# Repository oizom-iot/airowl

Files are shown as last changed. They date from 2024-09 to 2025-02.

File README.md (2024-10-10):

<div align="center">

# **AIROWL**

The OIZOM Airowl is an indoor Air Quality Measurement device comprising of the ESP32 S3 powered M5stack Core S3 SE, which integrates the aforementioned controller chip, with a 320 x 240 LCD screen supporting capacitive touch, along with a speaker and the AXP2101 power management chip.

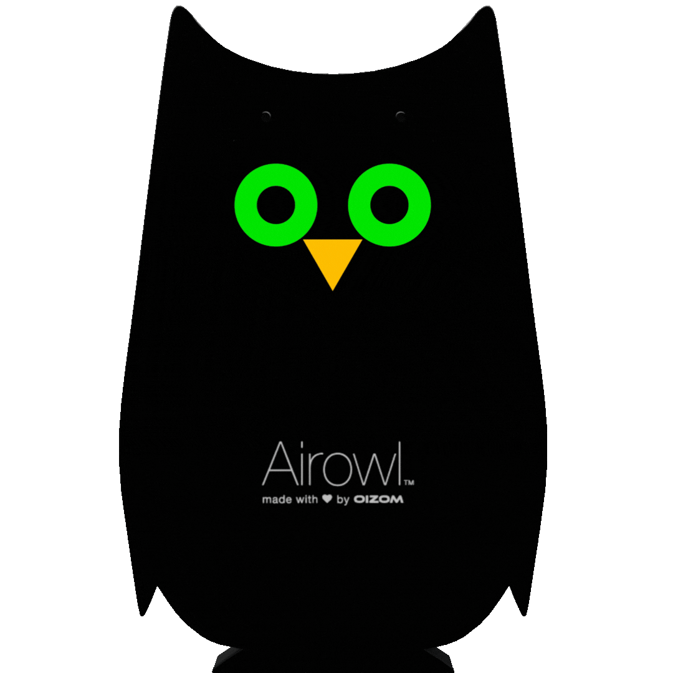
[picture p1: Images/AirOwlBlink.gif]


</div>

This Repository serves as the source of the complete Airowl, consisting of its Firmware source files, 3D files and PCB design Files.

This file provides instructions to assemble the individual components of the Airowl, along with its Bill of Materials (BOM).

The BOM for the Airowl is as Follows:

| SR. | ITEM DESCRIPTION | NOTES | Qty | Product Links |
|-----|---|---|-----|---|
| 1 | M5 STACK | SCREEN | 1 | <a href="https://shop.m5stack.com/products/m5stack-cores3-se-iot-controller-w-o-battery-bottom" target="_blank">Link</a> |
| 2 | FRONT FACIA | UV FRONT 1.3 MM + REAR BLACK 5 MM | 1 | [Front](/Designfiles/Frontfacia) |
| 3 | 3D PRINT BACK CASE | BLACK MATTLE 3D PRINTED CASE | 1 | [Back](/Designfiles/Backcover) |
| 4 | FASTENERS | M3 X 8 mm PHILIPS HEAD (SS) | 2 | |
| 5 | FASTENERS | M3 X 20 mm CSK Blunted (SS) | 2 | |
| 6 | FASTENERS | M3 X 25 mm CSK Blunted (SS) | 2 | |
| 7 | Screw Driver (+) | Mini Screw Driver | 1 | |
| 8 | TYPE C - TYPE C CABLE | PORTRONICS TYPE C CABLE | 1 | |

More details of the individual components can be found as followed:

[PCB files](/Mountingboard/)

[Firmware](/Firmware)

[Squareline studio project files](/squareline/) 

[Design Files](/Designfiles/)

## Assembling the Airowl

The following is a cross sectional view of the Airowl dpicting its individual components and the way that they must be connected:

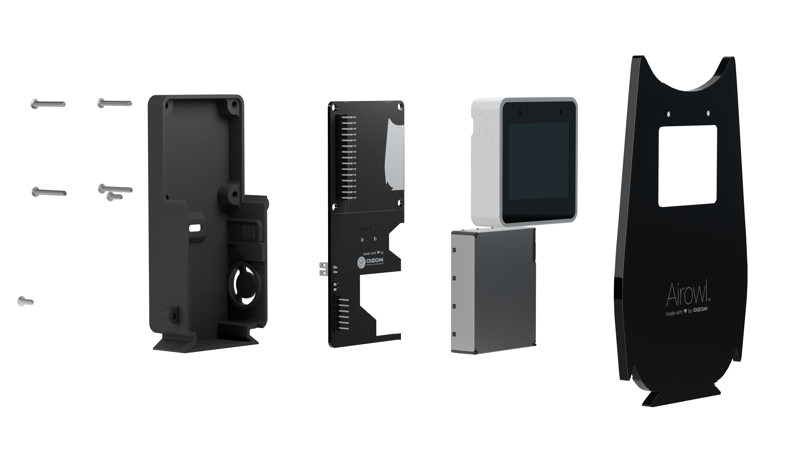
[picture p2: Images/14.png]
Design Files


From left to right, we can observe the parts as follows:

1. Screws
2. [3D printed Black Case](Images/16.png)
3. [Printed circuit Board](Images/19.png)
4. M5 stack Core S3 SE
5. Sensirion SEN 54 sensor
6. [Front Cover](Images/15.png)

Ensure that the screws are connected correctly as depicted in the above picture, incase the screws are connected incorrectly, the longer screws might damage the physical cover of the Airowl.

On assembling the Airowl, it appears like depicted below:



On following the instructions in [Firmware](/Firmware/), the Airowl can be programmed succesfully.

Check this repository releases for newer firmware updates.

## Made by the Community, with -❤️-:

<a href="https://github.com/oizom-iot/airowl/graphs/contributors">
  
</a>

## Licensing

Airowl is available under MIT License

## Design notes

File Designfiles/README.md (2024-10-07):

# Design files

## 3MF File for 3D Printing
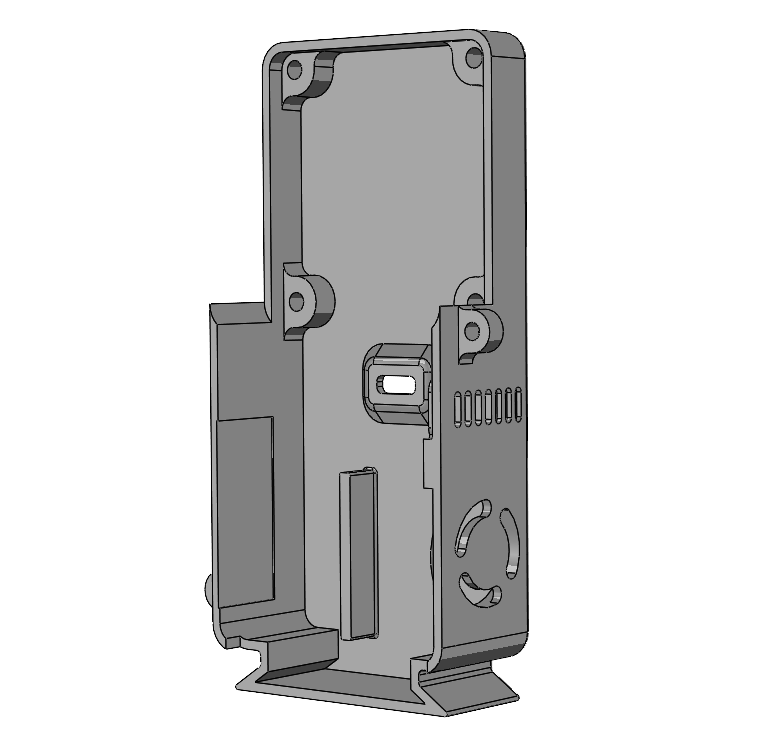
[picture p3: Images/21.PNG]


### Suggestions for 3D printing
- **Material**: PLA+
- **Color**: Matte Black
- **Print Quality**:
  - 0.15mm layer for 0.4mm nozzle
  - Use 0.08mm layer for better quality

## DXF Files for Laser Cutting

- **Transparent Acrylic Sheet (Front Facia)**
  - Thickness: 1mm ± 0.2mm

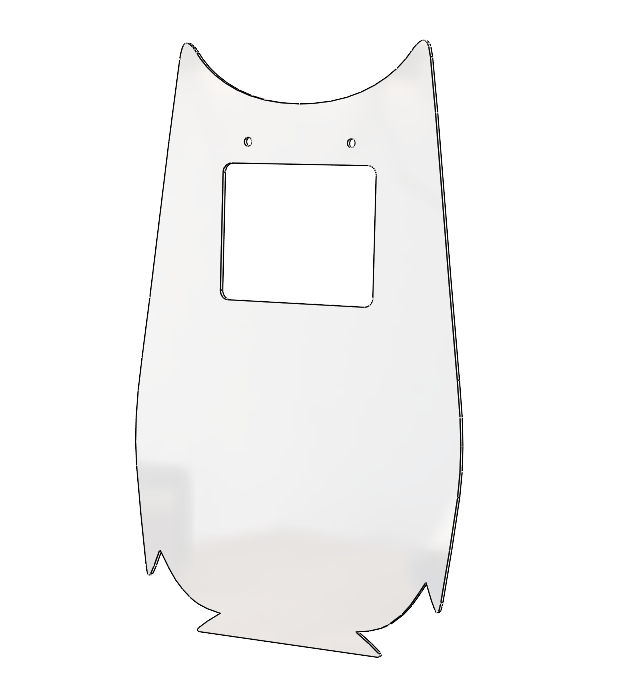
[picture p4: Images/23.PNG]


- **Black Acrylic Sheet (Front Facia)**
  - Thickness: 5mm

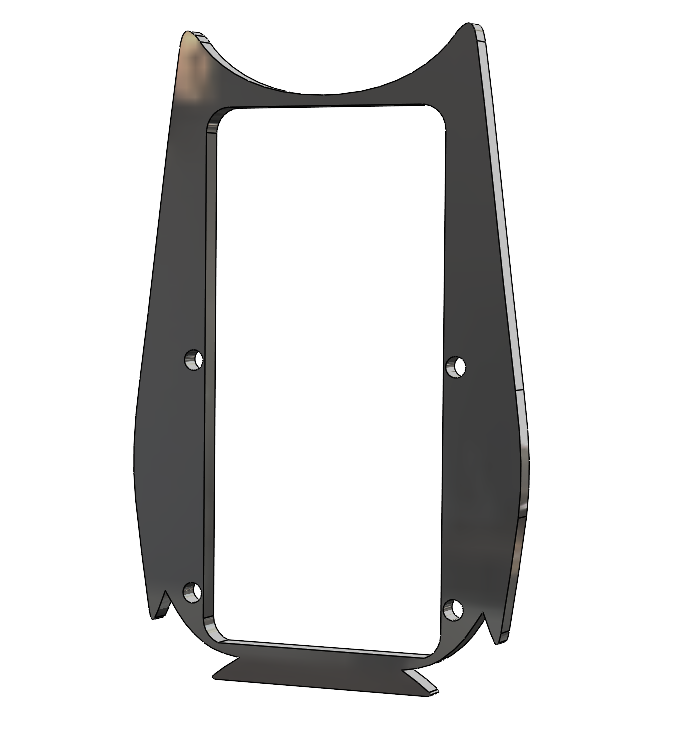
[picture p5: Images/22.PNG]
 

## PDF File for UV Printing

- **Print on transparent Acrylic Sheet**
  - **Color**: Black

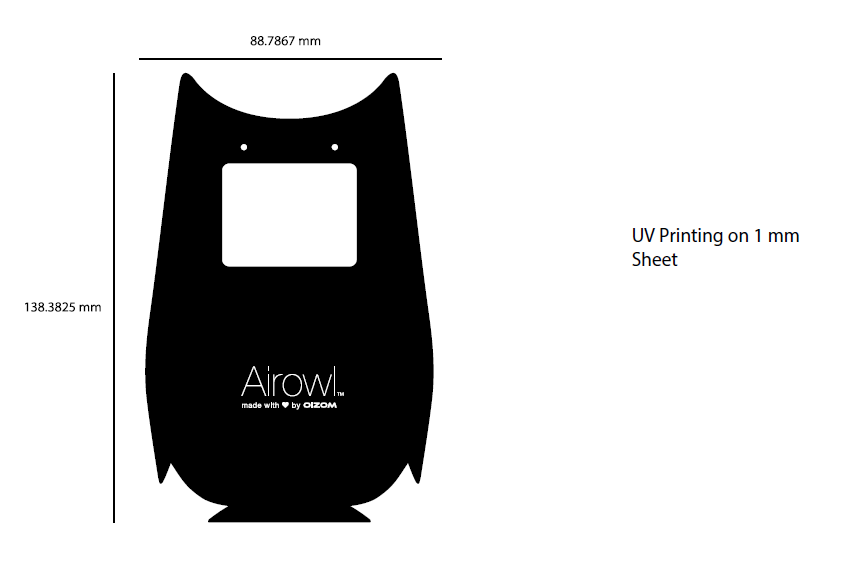
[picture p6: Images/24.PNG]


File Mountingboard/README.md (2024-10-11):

# Open Source PCB Design for M5Stack and Sensirion Dust Sensor SN54





This repository contains the open-source PCB design created using **KiCAD** software. The design includes both the schematic and the PCB layout.

---

## Table of Contents
- [Project Overview](#project-overview)
- [Key Features](#key-features)
- [Schematic and PCB Design](#schematic-and-pcb-design)
  - [Schematic](#schematic)
  - [Rendered PCB Images](#rendered-pcb-images)
- [Bill of Materials (BOM)](#bill-of-materials-bom)
- [How to Use](#how-to-use)
- [Contributing](#contributing)
- [License](#license)

---

## Project Overview

This PCB design integrates the **M5Stack** and the **Sensirion Dust Sensor SN54**, which measures the following parameters:

- **PM1**
- **PM2.5**
- **PM10**
- **Temperature**
- **Humidity**
- **TVOC Index**

The design facilitates I2C communication between the M5Stack and the dust sensor, with electrical connections labeled and organized for simplicity.

### Key Features

- **I2C Communication**: The M5Stack communicates with the Sensirion Dust Sensor via I2C.
- **Type-C Power Supply**: The entire PCB is powered through a Type-C connector.
- **Sensor Connections**: The wires from the sensor are soldered onto the PCB, with labeled footprints for I2C and 5V power connections.

---

## Schematic and PCB Design

The repository includes:

- **Schematic**: Showing the connection between M5Stack and Sensirion Dust Sensor SN54.
- **PCB Design**: Footprint and layout for soldering sensor wires and powering the device.

### Schematic

<details>
  <summary>Click to expand Schematic image</summary>
  
  Schematic

</details>

### Rendered PCB Images

- **Front View**
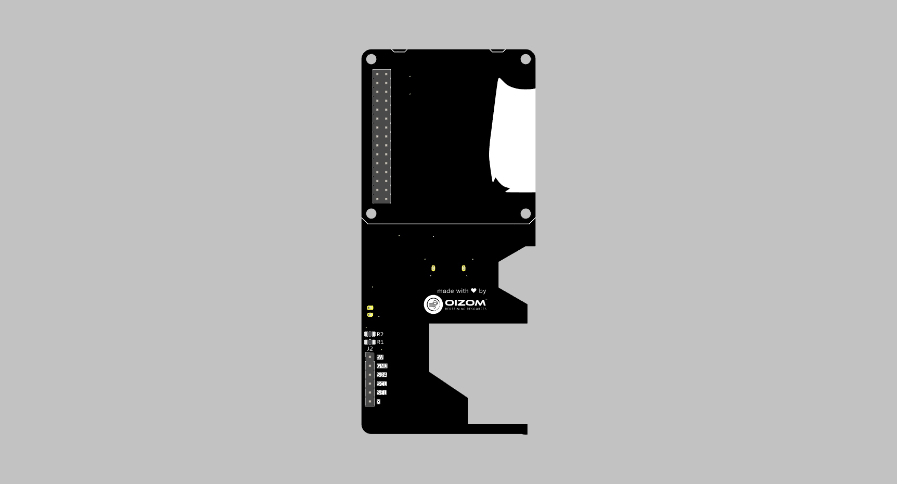
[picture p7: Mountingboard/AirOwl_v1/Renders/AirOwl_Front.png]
Front View


- **Back View**
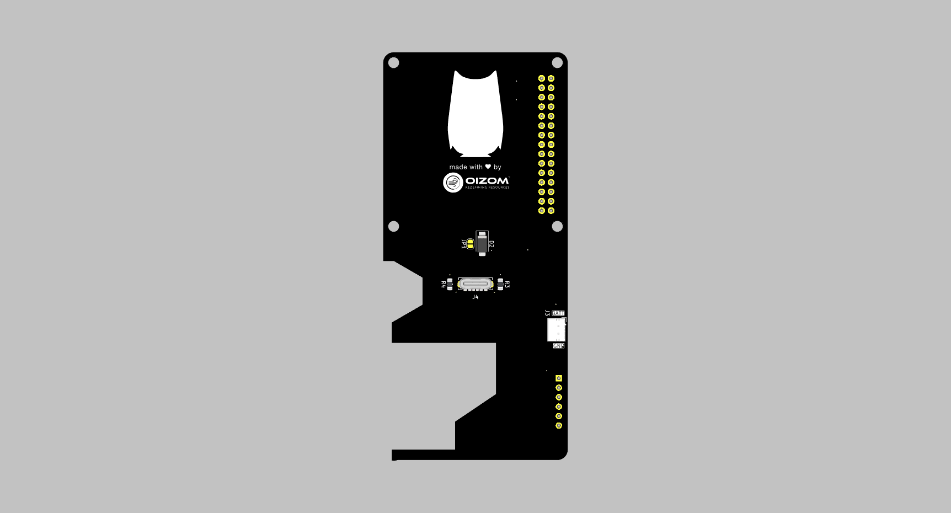
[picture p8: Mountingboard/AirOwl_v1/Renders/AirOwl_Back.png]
Back View


---

## Interactive BOM

You can download the Interactive BOM [here](AirOwl_v1/bom/ibom.html).



> **Note**: Right-click the link and select "Open Link in New Tab" or press `Ctrl + Click` to open in a new tab.

## Bill of Materials (BOM)

| Part Name | Quantity | Reference Link |
|---|---|---|
| **M5Stack CoreS3-SE** | 1 | <a href="https://shop.m5stack.com/products/m5stack-cores3-se-iot-controller-w-o-battery-bottom" target="_blank">Link</a> |
| **Sensirion Dust Sensor SEN54**| 1 |  <a href="https://www.digikey.in/en/products/detail/sensirion-ag/SEN54-SDN-T/15903868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" target="_blank">Link</a> | 
| **Type-C Connector** | 1 |  <a href="https://www.digikey.in/en/products/detail/same-sky/UJC-VP-3-SMT-TR/14310522?productid=14310522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">Link</a> | 
| **I2C Pull-up Resistors [R1, R2]** | 2 | 10K 0805 (Optional) | 
| **Resistors [R3, R4]** | 2 | 4.7K 0805 (Must for Type C PD) | 
| **Male Header Pin** | 1 | 2.54mm 40x2 Male Header Pin | 
| **Sensirion Dust Sensor Cable** | 1 | <a href="https://evelta.com/jst-ghr-06v-cable-6pin-1-25mm-pitch-female-connector-15cm/" target="_blank">Link</a> | 

> **Note:** This table will be updated with detailed part information.

---

## How to Use

To get started with this PCB design:

```bash
# Step 1: Clone the repository
git clone https://github.com/your-repo-name.git

# Step 2: Open the project in KiCAD

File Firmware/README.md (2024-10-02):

# Firmware

This folder contains the firmware files used to program the Airowl. The Folder consists of various folders used by PlatformIO to configure and program the project.

## Using PlatformIO
PlatformIO is a VS code extension that enables us to program microcontrollers using VS code. The PlatformIO core supports more than 1500 development boards including the M5 core S3 used in the Airowl. PlatformIO supports both esp-idf and arduino environments. 

### Step 1  Installing PlatformIO 
PlatformIO can be installed using the extensions feature in Visual Studio Code.

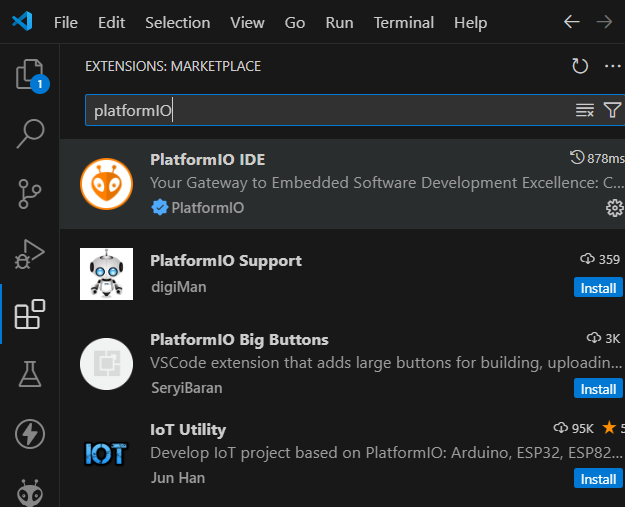
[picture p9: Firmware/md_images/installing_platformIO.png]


### Step 2 Using PlatformIO with Airowl Firmware

In order to program the Airowl with the firmware, download and extract this repository or clone it.
Open platformIO using the platformIO icon from the sidebar.

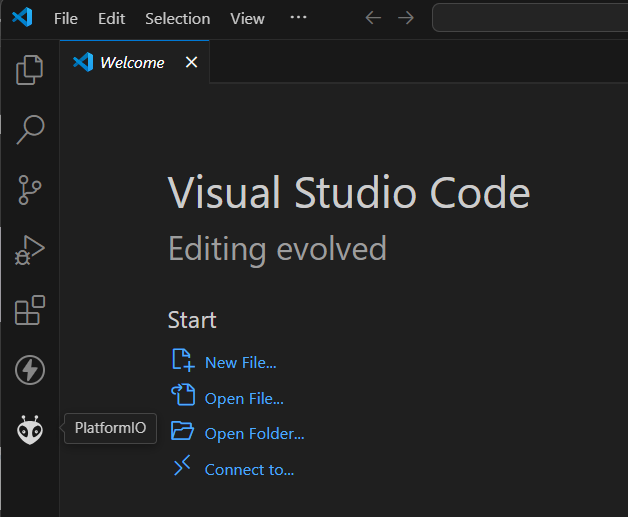
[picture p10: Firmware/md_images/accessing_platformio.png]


Open PIO home to access platformIO, this opens a new tab in VS code which can be used to create/open projects.

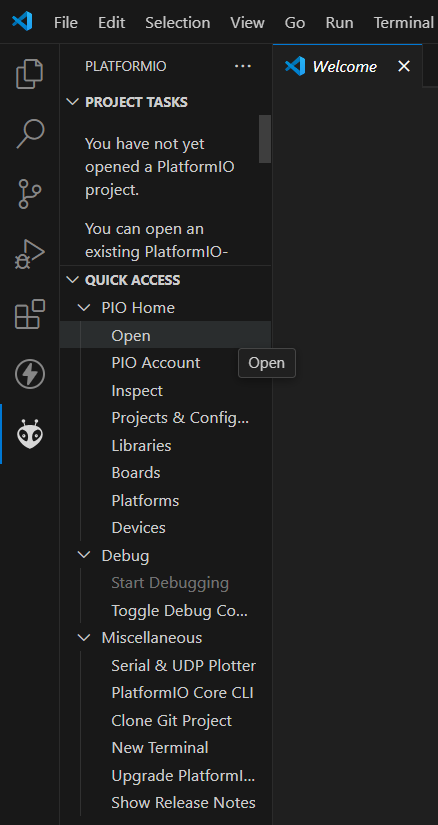
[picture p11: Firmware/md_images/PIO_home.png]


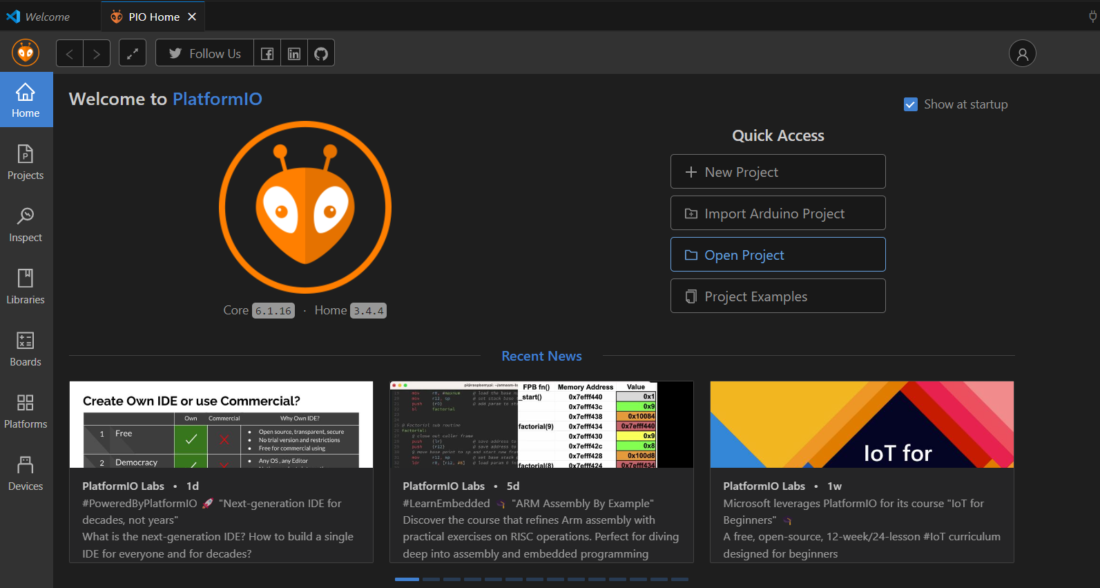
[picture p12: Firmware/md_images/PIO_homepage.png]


Click on Open Project button as highlighted in the above picture and locate the downloaded repository, and open the Firmware folder. Ensure that the folder has platformio.ini file present in it as this file acts as the config file for platformio and is essential to program the firmware to the Airowl. 

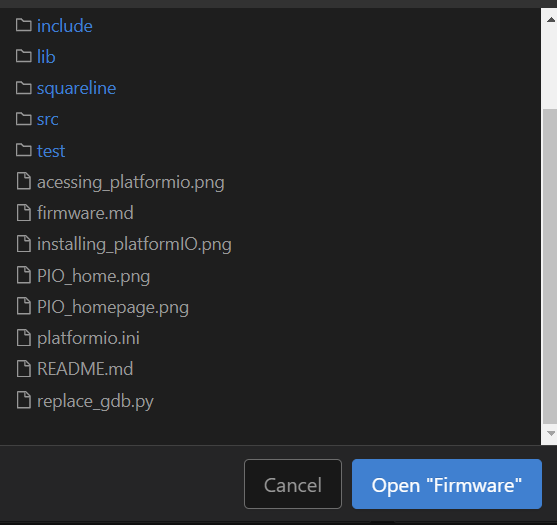
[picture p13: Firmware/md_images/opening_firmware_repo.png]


### Step 3  Uploading to the device using PlatformIO

Once the platformio.ini file is loaded, ensure that Airowl is connected to your PC, and upload the firmware using the PlatformIO : upload button



The terminal displays the upload status and on Successful upload displays the following :

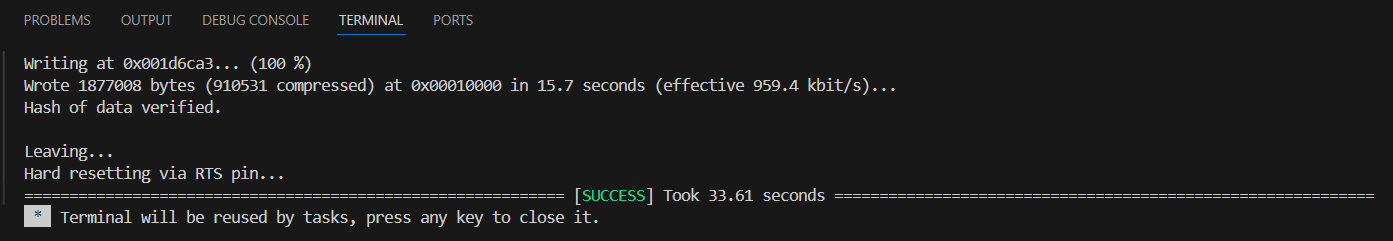
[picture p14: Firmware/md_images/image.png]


## Squareline Studio

[Squareline Studio](https://squareline.io/) is a software that enables us to develop User Interface using LVGL, such that the tool converts visual design into LVGL based code allowing us to integrate images, logos, etc. in the project. 

[Squareline Studio Documentation](https://docs.squareline.io/docs/squareline/) 

Inside the firmware folder, the directory named [Squareline](/squareline/) stores the project files from squareline studio, these files contain the UI design.

### Step 1. Opening the Squareline Studio Project Files

[example_project.spj](/squareline/projects/ui_square_line/example_project.spj) is the squareline studio project file.

On launching Squareline Studio, click on the Import project button using which [example_project.spj](/squareline/projects/ui_square_line/example_project.spj) can be located and opened and modified accordingly.

On opening the project, we can see the various UI elements used to create the UI - such as the screens, images, buttons and the graphs created to portray the changing values of the parameters - measured using the SEN 54 sensor. 
Custom animations have been made for the Airowl with events created to trigger them.

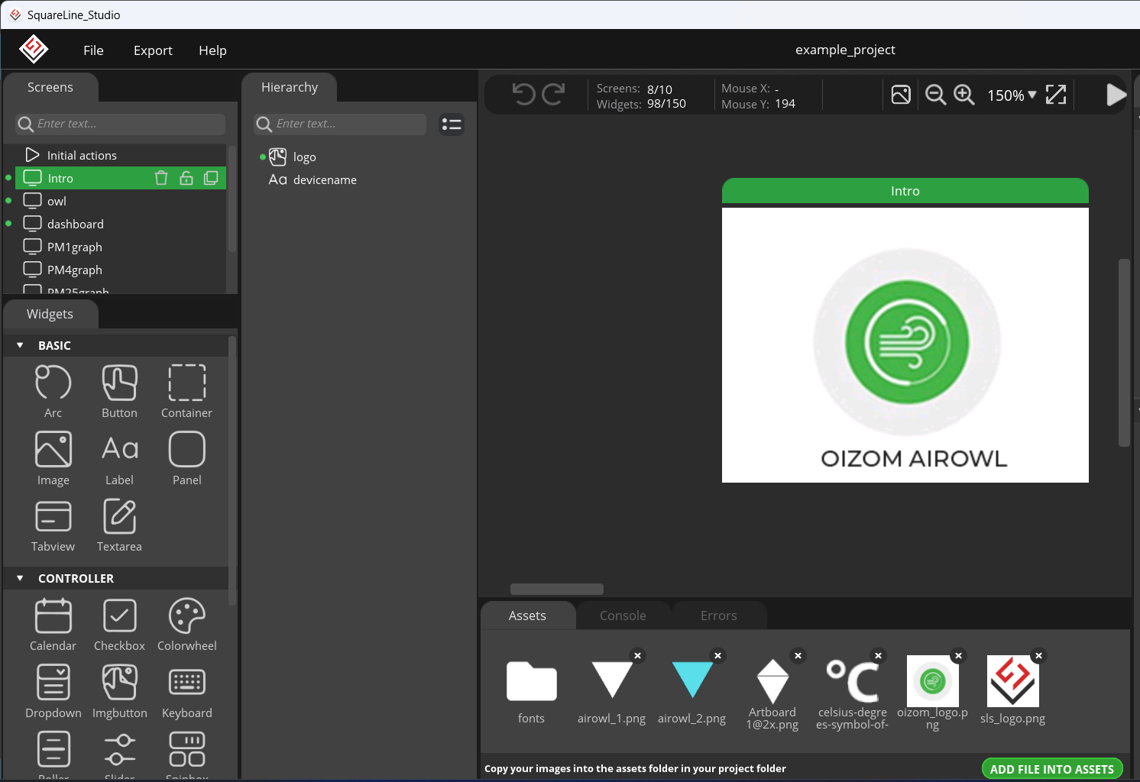
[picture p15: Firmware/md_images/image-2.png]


The screens panel on the side is jused to handle the screens, whereas  Widgets tab is used to add buttons/ containers/ labels etc.

The assets tab below the screens view is used to add images/ fonts to be used in the design.
Using the Add File into ASSETS option, more images can be added into the project.

On selecting the appropriate screen , the elements inside it are visible in the Heirarchy tab.

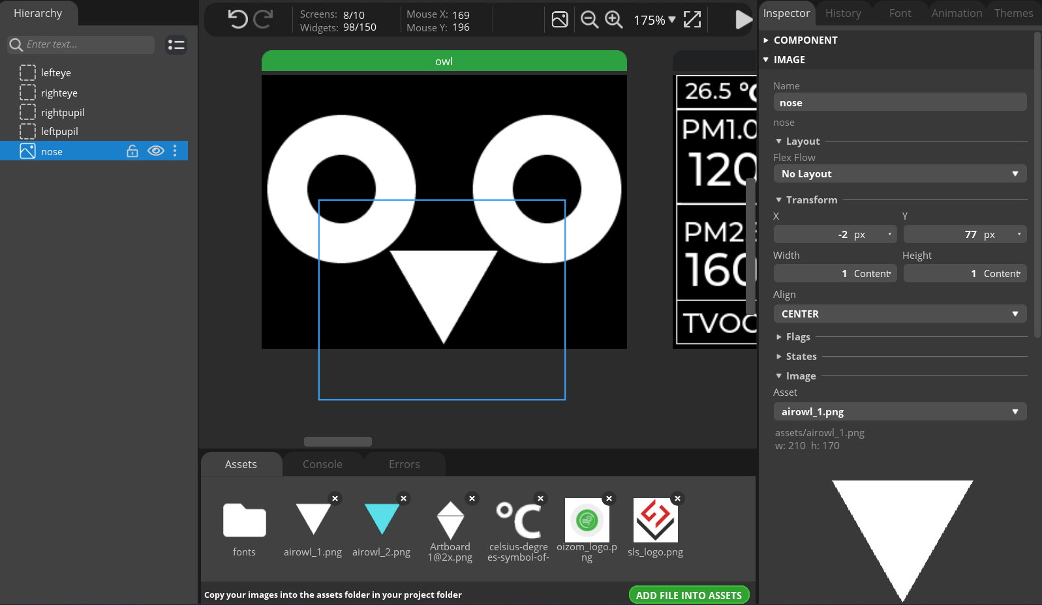
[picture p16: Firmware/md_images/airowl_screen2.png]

On selecting the element, we can modify the properties of the element through the inspector tab on the right such as size, position.
The font tab is used to handle the fonts used in the project.

The animation tab is usd to create/modify animations, the animations can be lated applied to different targets in the inspector tab.
The animations can be binded to events based on screen touch/ timeout basis from the inspector tab.

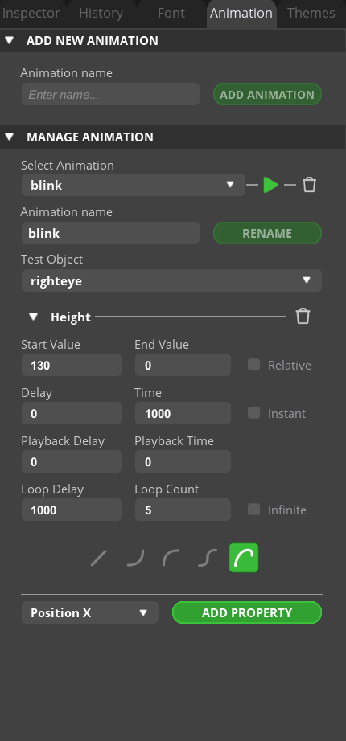
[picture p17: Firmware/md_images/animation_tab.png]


The white play button on the top (left of Inspector tab) can be clicked to simulate the animation, before using it in the Firmware.

### Step 2. Exporting the UI Files
Once the UI has been created , it is time to export the UI files. This can be done using the Export option on the top-left of the window. However, we must first ensure that the UI export path is correctly set inside the correct directory, this can be done using the file -> project settings option as depicted below:

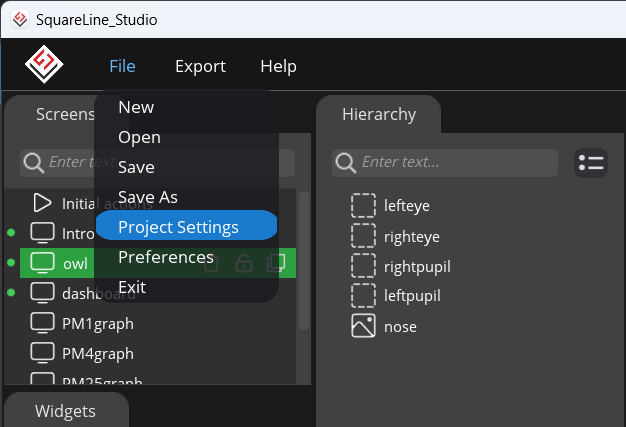
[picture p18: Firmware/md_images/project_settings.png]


It must be ensured that the Project export path is [ui_square_line](/squareline/projects/ui_square_line/) and the UI files export path is set to [/src/m5stack/ui/](/src/m5stack/ui/), this ensures that on updating the UI and exporting the UI files through Squareline Studio, the changes are reflected in the Firmware.

## src/m5stack

This folder contains the main files of the firmware. The C files, header files , UI files are all located inside this directory.

### ui
This folder contains the exported UI files from squareline studio (in source code format)

The fonts folder contains the custom fonts that we had added in the assets folder in squareline studio, the images folder contains the images used for the UI in C code, while the screens folder contains the C files for the various screens used in the UI design.
These files declare and use different objects to display the elements on the 320 x 240 LCD screen of the Airowl. Referencing these objects, and their types, we can manipulate them accordingly in order to update the UI based on sensor data and touch events.

The ui.c and ui.h files define all the animation functions, the labels, the conatiners and the objects that are used in the UI.These files also bind these objects to their repective LVGL components.

### main.cpp

Similar to Arduino IDE's .ino files, the main.cpp file consists of the setup() and loop() functions, this is actually the file executed by the platformIO core. It consists of inclusion of other header and UI files, which facilitates the usage of UI, and allows the functioning of I2C,Wifi,RTOS, MQTT functionality.
### Sensor.h 

The Sensor.h file acts as the backbone of the firmware. It defines and calls most functions required by the firmware.

To handle the SEN54 sensor, the file utilizes the appropriate library - <SensirionI2CSen5x.h>, this is the original arduino platform library, and handles the SEN 54 .

The Wire.h is the standard library used to handle I2C communication between the M5 Core S3's ESP32S3 microcontroller and the sensor. The M5 coreS3 and SEN 54 have interfaced as follows: 

1. SEN 54 VDD -> 5V 

2. SEN 54 GND -> GND

3. SEN 54 SCL -> G1

4. SEN 54 SDA -> G2

5. SEN 54 SEL -> GND    

Refer to the Pinmap of M5 core S3 SE below:

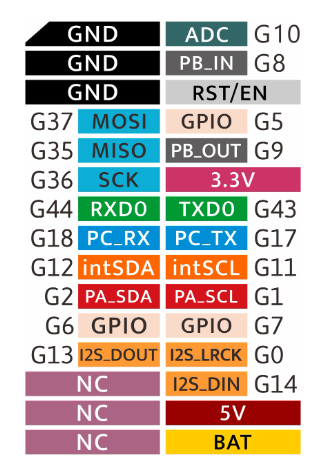
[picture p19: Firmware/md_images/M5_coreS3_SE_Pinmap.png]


Various LVGL UI objects are used in this file to overwrite/update the values displayed on the screen.
A data frequency of 150 has been defined which ensures that the graphs depicting PM1.0, PM 2.5, PM 4.0, PM 10.0 and TVOC are updated every 5 mins.

The live data is displayed on the dashboard screen, where the screen is divided into buttons, on touching the corresponding button, the graph of its parameter is displayed.

Functions - getAQIBreakpoint and getAQIColor are used to quantify the air quality index based on the PM and TVOC values, based on the AQI, the colors on the dashboard and the Owl screen are also updated.

Moreover Wifi.h and PubSubClient.h files are included to facilitate Wifi and MQTT functionalities respectively.

### time_func.h

This File handles the syncronization of the time label on the dashboard screen with the NTP server, using WifiManager functions.

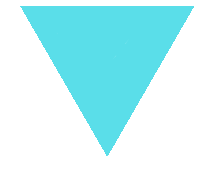
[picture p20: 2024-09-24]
Firmware/squareline/projects/ui_square_line/assets/airowl_2.png

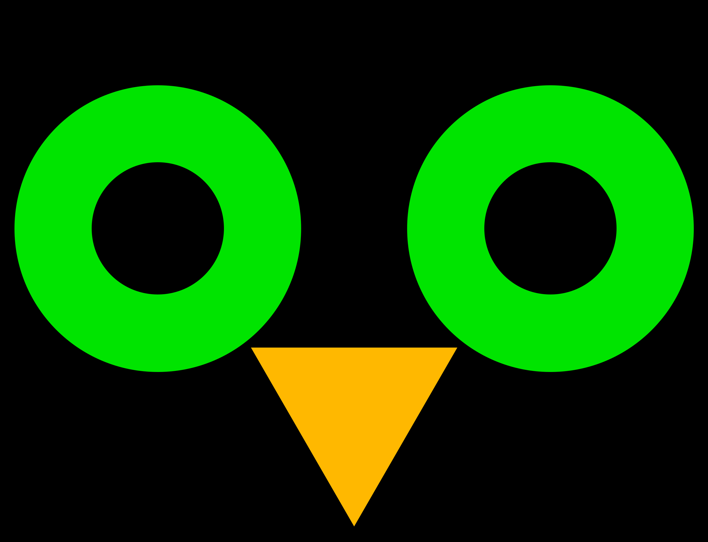
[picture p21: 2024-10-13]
Images/OWL-FACE-ANI.gif

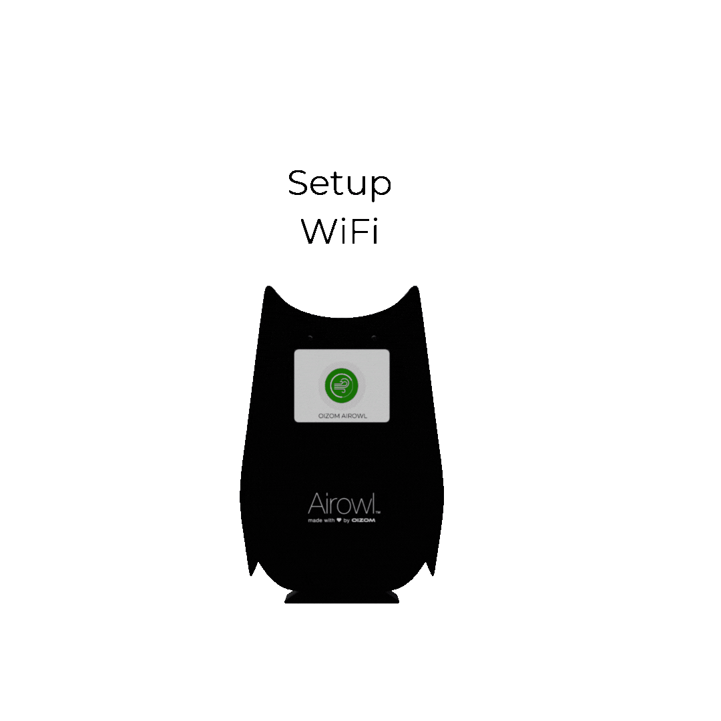
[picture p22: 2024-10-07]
Images/AirowlGIF.gif

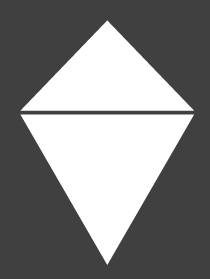
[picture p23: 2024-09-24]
Firmware/squareline/projects/ui_square_line/assets/Artboard 1@2x.png

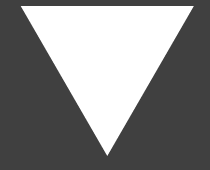
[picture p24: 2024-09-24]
Firmware/squareline/projects/ui_square_line/assets/airowl_1.png

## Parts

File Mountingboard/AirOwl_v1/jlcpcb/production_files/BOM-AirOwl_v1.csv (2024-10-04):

Comment | Designator | Footprint | LCSC
10K | R2 | R_0805_2012Metric_Pad1.20x1.40mm_HandSolder
10K | R1 | R_0805_2012Metric_Pad1.20x1.40mm_HandSolder
Conn_01x06 | J2 | PinHeader_1x06_P2.54mm_Vertical
USB_C_Receptacle_PowerOnly_6P | J4 | MOLEX_2171780001
USB_C_Receptacle_PowerOnly_6P | J1 | USB-C_6P_Vertical_THT
SS34 | D2 | D_SMA
CoreSE | U1 | CoreS3
Conn_01x02 | J3 | JST_PH_B2B-PH-K_1x02_P2.00mm_Vertical

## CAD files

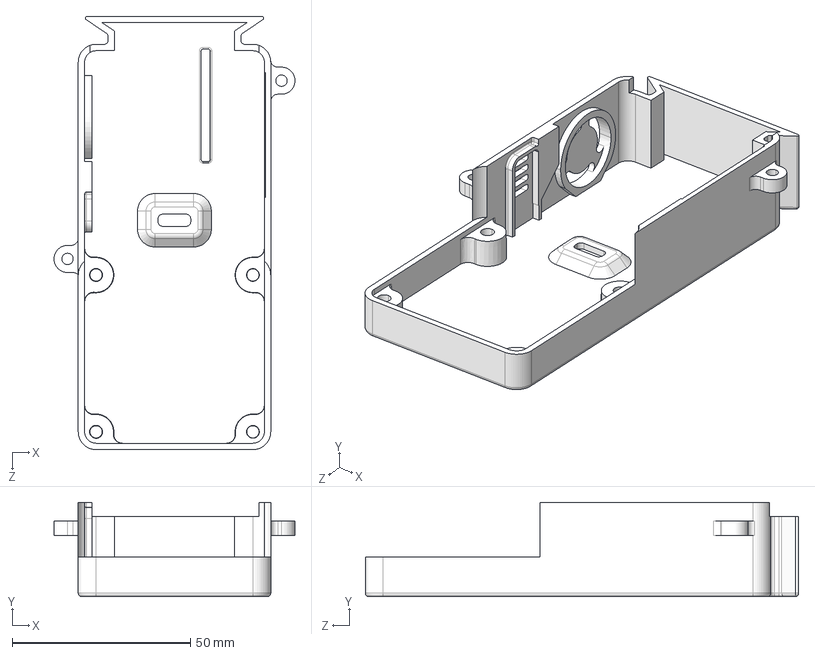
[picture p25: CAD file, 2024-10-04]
Designfiles/Backcover/Owl_2.0_component_case_V2.4.4.STEP
67.6 x 26.5 x 121.5 mm

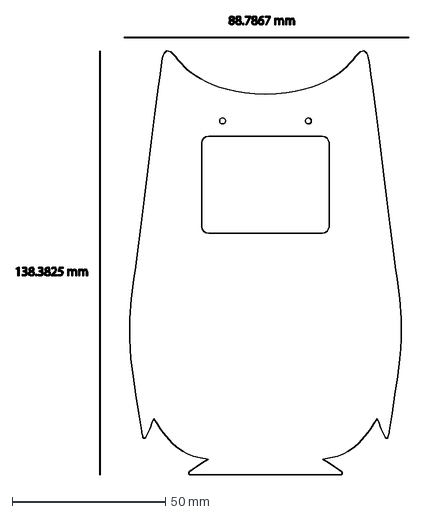
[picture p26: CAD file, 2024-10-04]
Designfiles/Frontfacia/Front facia 1mm.dxf
128.2 x 149.8 mm

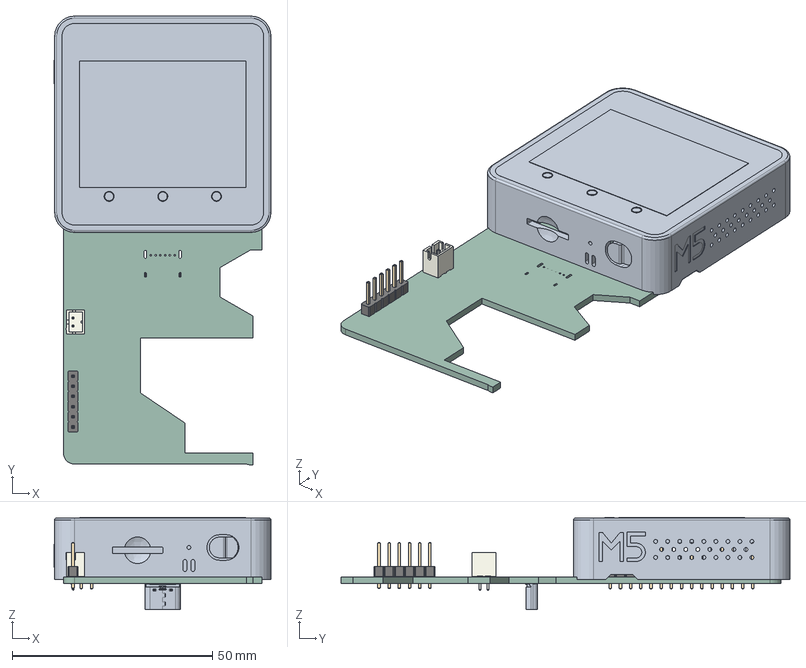
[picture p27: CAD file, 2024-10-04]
Mountingboard/AirOwl_v1/3D/AirOwl_v1.step
54.2 x 112.0 x 23.0 mm
PinHeader_1x06_P254mm_Vertical
JST_B2B_PH_K
PinHeader_2x15_P254mm_Vertical
M5Stack_Core2(2)^M5Stack_Core2
AirOwl_v1_PCB_1
AirOwl_v1_PCB_2
AirOwl_v1_PCB_3
AirOwl_v1_PCB_4
AirOwl_v1_PCB_5

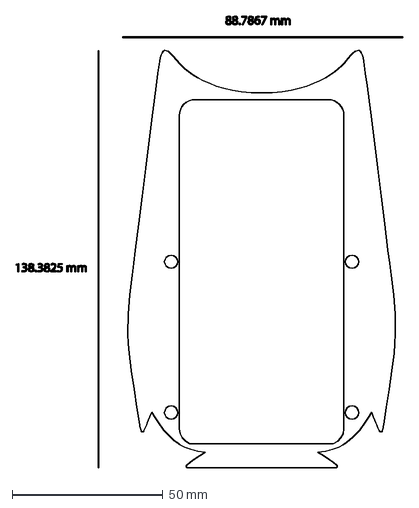
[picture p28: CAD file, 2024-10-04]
Designfiles/Frontfacia/Facia back plate 5mm (Black).dxf
128.2 x 149.8 mm

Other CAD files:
Designfiles/Backcover/Owl_2.0_component_case_V2.4.4.3MF

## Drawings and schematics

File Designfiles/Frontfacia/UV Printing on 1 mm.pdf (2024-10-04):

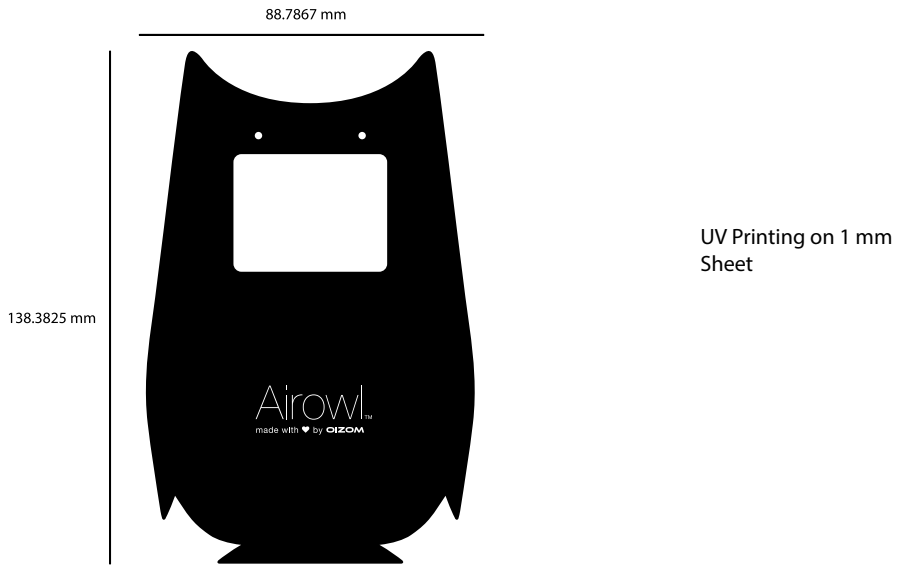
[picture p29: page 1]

UV Printing on 1 mm
Sheet

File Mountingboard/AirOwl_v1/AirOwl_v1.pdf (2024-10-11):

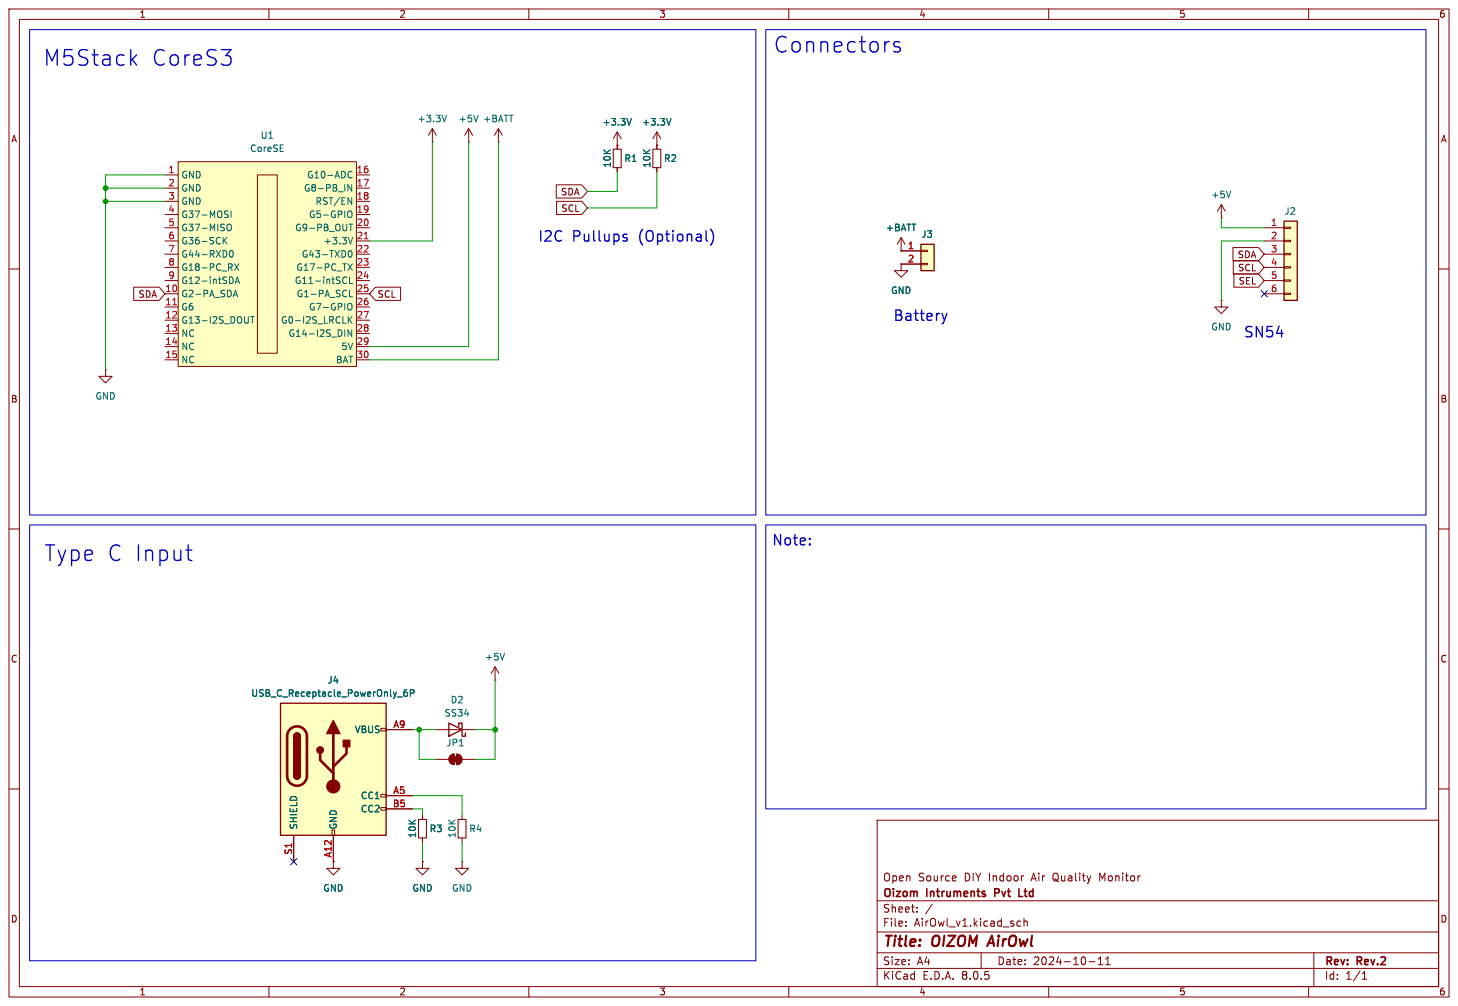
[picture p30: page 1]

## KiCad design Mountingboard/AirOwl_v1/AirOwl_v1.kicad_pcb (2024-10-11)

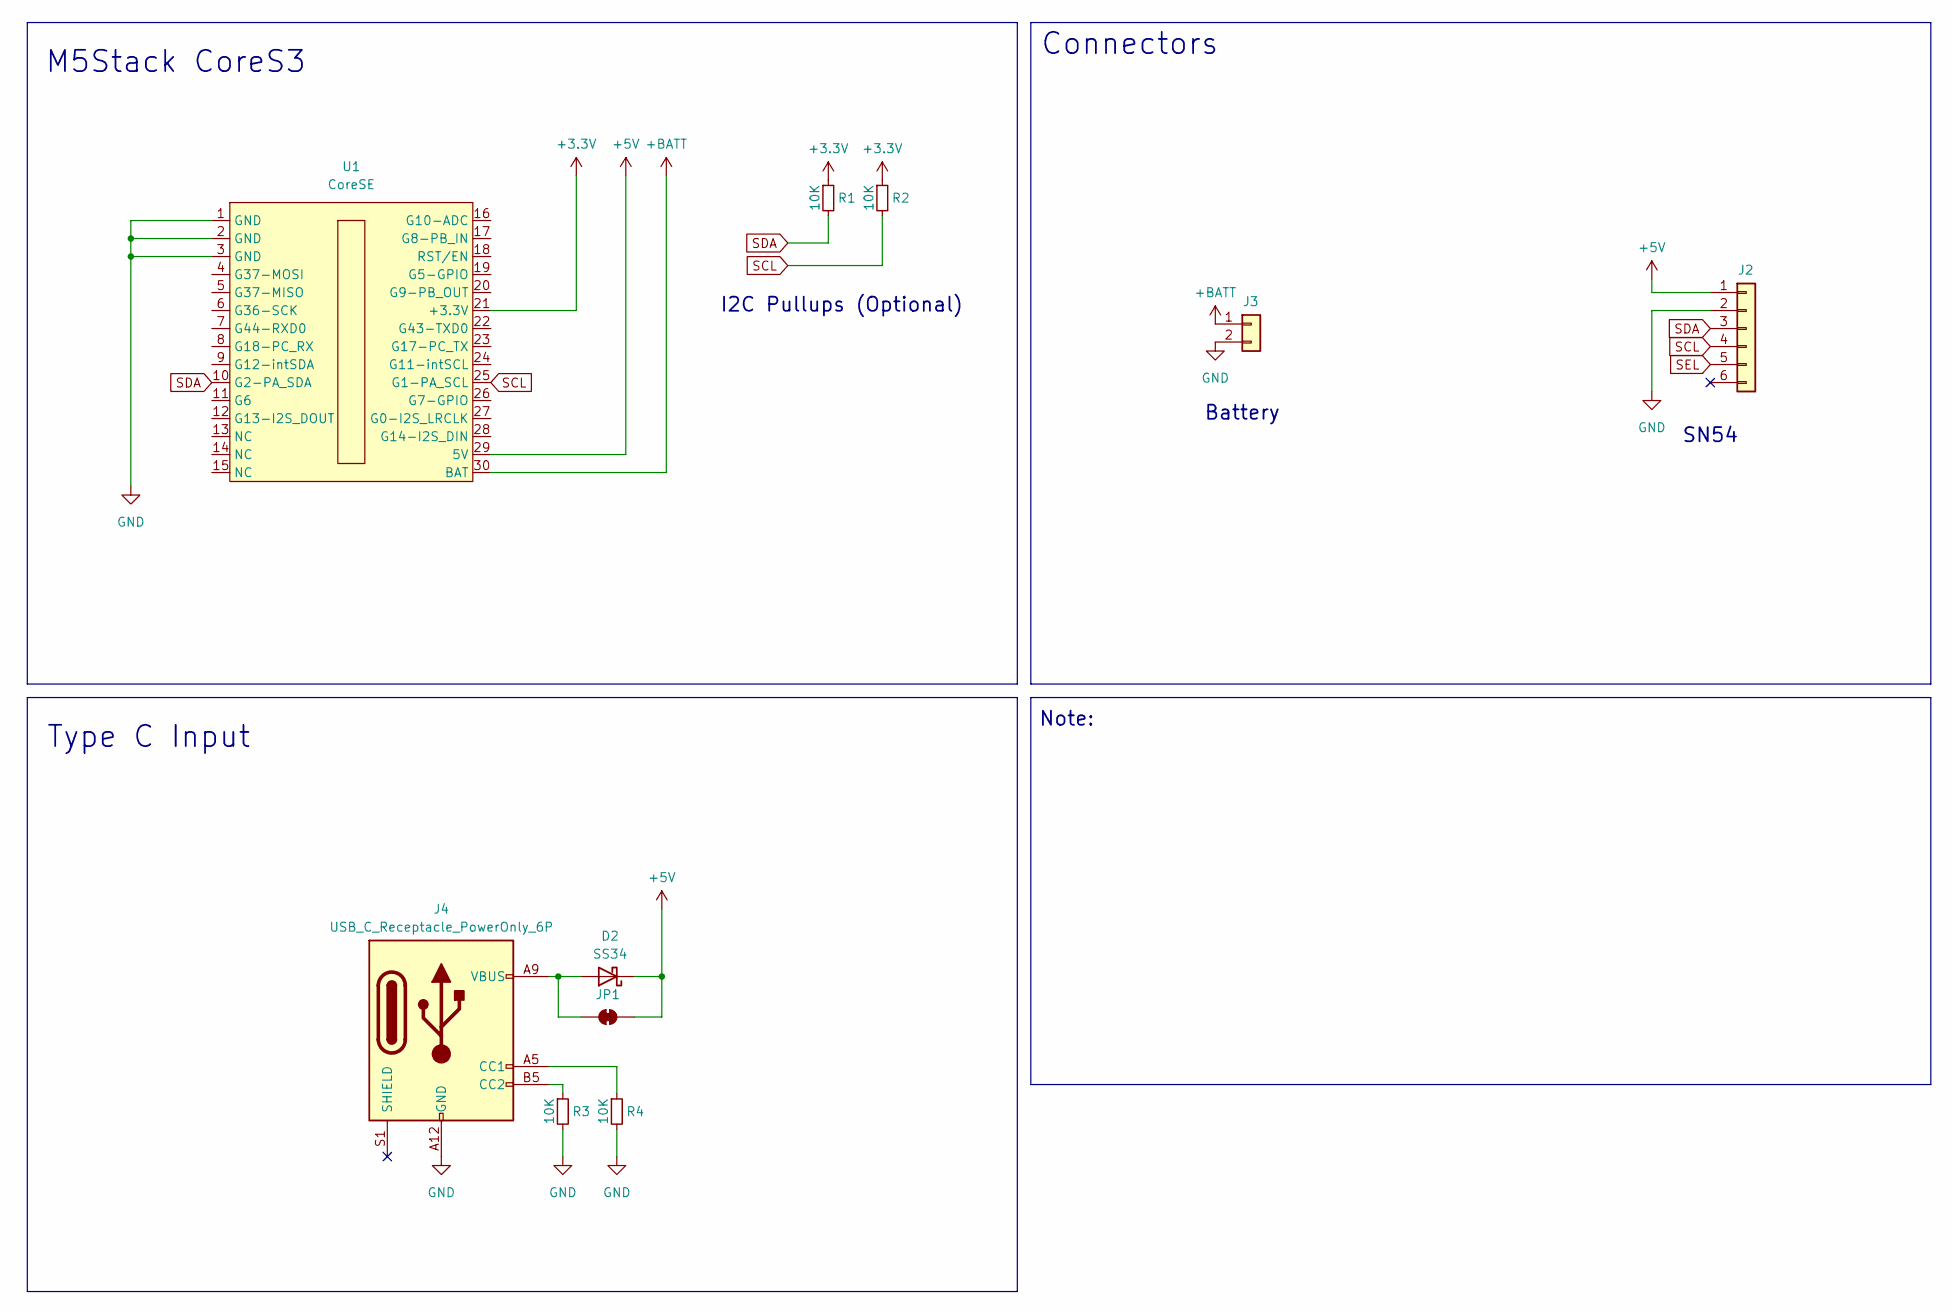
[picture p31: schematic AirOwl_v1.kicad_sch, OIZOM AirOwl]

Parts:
D2: SS34; D_SMA
J2: Conn_01x06; PinHeader_1x06_P2.54mm_Vertical
J3: Conn_01x02; JST_PH_B2B-PH-K_1x02_P2.00mm_Vertical
J4: USB_C_Receptacle_PowerOnly_6P; MOLEX_2171780001
JP1: SolderJumper_2_Bridged; SolderJumper-2_P1.3mm_Bridged_RoundedPad1.0x1.5mm
R1, R2, R3, R4: 10K; R_0805_2012Metric_Pad1.20x1.40mm_HandSolder
U1: CoreSE; CoreS3

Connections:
+3.3V: R1.1, R2.1, U1.21 (+3.3V)
+5V: D2.1 (K), J2.1, JP1.2 (B), U1.29 (5V)
+BATT: J3.1, U1.30 (BAT)
GND: J2.2, J3.2, J4.A12 (GND), J4.B12 (GND), R3.2, R4.2, U1.1 (GND), U1.2 (GND), U1.3 (GND)
unnamed: D2.2 (A), J4.A9 (VBUS), J4.B9 (VBUS), JP1.1 (A)
unnamed: J4.A5 (CC1), R4.1
unnamed: J4.B5 (CC2), R3.1
SCL: J2.4, R2.2, U1.25 (G1-PA_SCL)
SDA: J2.3, R1.2, U1.10 (G2-PA_SDA)
SEL: J2.5

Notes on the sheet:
Battery
I2C Pullups (Optional)
M5Stack CoreS3
Type C Input
Connectors
SN54
Note:

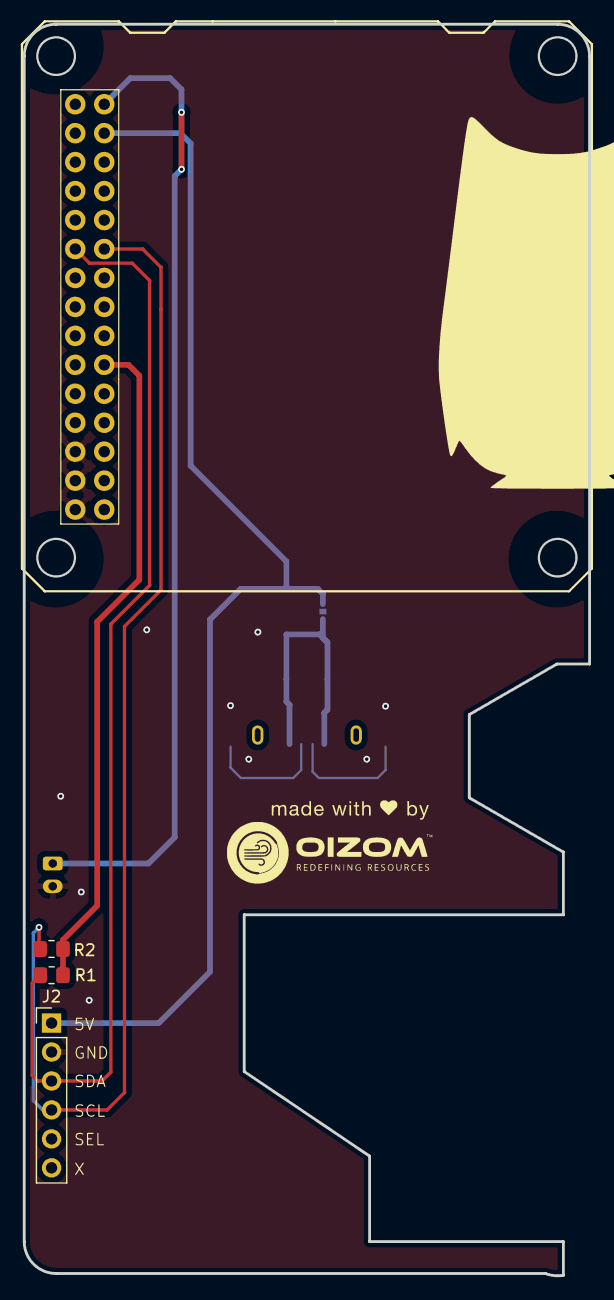
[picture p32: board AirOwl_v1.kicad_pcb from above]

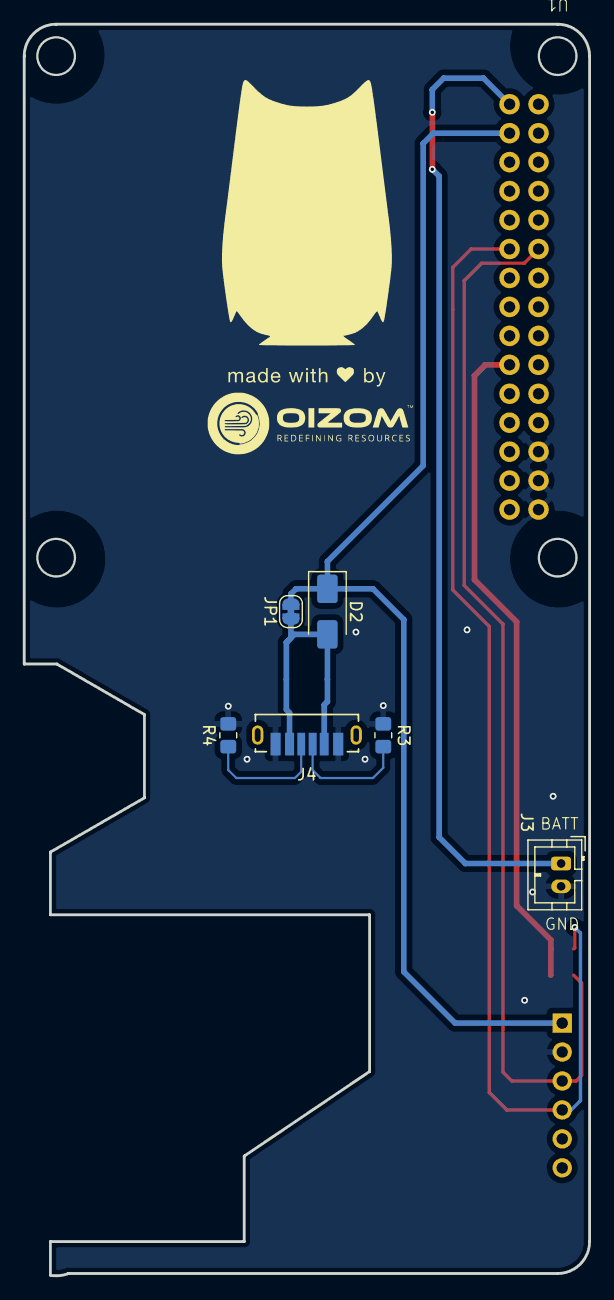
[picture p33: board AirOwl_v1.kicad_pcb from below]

Board: 2 copper layers, 49.6 x 109.8 mm, 10 parts (7 on the bottom side), 9 nets.

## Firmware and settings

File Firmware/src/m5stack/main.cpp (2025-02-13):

#include <Arduino.h>
#if defined(ARDUINO_M5STACK_Core2)
#include <M5Core2.h>
#endif
#if defined(ARDUINO_M5STACK_CORES3)
// #include <M5CoreS3.h>  // no touch support yet
#include <M5Unified.h>
#endif
#include <esp_task_wdt.h>
#include <WiFiManager.h> 
#include <WiFiManagerTz.h>
#include "Sensor.h"
#include "ui/lv_setup.h"
#include "ui/ui.h"
#include "config.h"
#include "time_func.h"
#include <FS.h>


#define WDT_TIMEOUT 60

#define FIRMWARE_VERSION "version - 1.1"

WiFiManager wm;
TaskHandle_t myTaskHandle;

void on_time_available(struct timeval *t)
{
  Serial.println("Received time adjustment from NTP");
  struct tm timeInfo;
  getLocalTime(&timeInfo, 1000);
  Serial.println(&timeInfo, "%A, %B %d %Y %H:%M:%S zone %Z %z ");
  M5.Rtc.setDateTime( &timeInfo );
}

void setup() {
  // Begin M5 Stack
  M5.begin();
  M5.Display.setRotation(3);
  if(M5.Rtc.isEnabled())
  {
    M5.Log.println("RTC Enabled");
  }

  // Initialize the Task Watchdog Timer
  esp_task_wdt_init(WDT_TIMEOUT, true); // Enable panic so ESP32 restarts
  
  // Add the current task to the watchdog (loopTask)
  esp_task_wdt_add(NULL); // NULL means current task
  
  // Get Mac Address to generate Unique Name
  String mac = WiFi.macAddress();
  mac.replace(":", "");
  String apName = "AIROWL_" + mac.substring(6);
  
  // Setup Wifi Manager NTP server
  WiFiManagerNS::NTP::onTimeAvailable( &on_time_available );
  WiFiManagerNS::init( &wm, nullptr );
  std::vector<const char *> menu = {"wifi", "info", "custom", "param", "sep", "restart", "exit"};

  // Enable WifiManager
  wm.setMenu(menu);
  wm.setConfigPortalBlocking(false);
  wm.setTitle("AIROWL Configuration");
  wm.autoConnect(apName.c_str(), "12345678");
  
  // Remove already saved wifi credentials
  // wm.erase();
  // Begin LVGL Display
  lv_begin();  // Initialize LVGL for the Core2 screen
  ui_init();   // Initialize UI generated by Square Line
  lv_label_set_text(ui_devicename, apName.c_str());
  lv_label_set_text(ui_qrcodename, apName.c_str());
  lv_label_set_text(ui_firmwareversion, FIRMWARE_VERSION);

  /*Set data*/
  String qrcodeurl = "";
  if(WiFi.status() == WL_CONNECTED)
  {
    qrcodeurl = "https://opendata.oizom.com/device/" + apName;
  }
  else{
    qrcodeurl = "WIFI:T:WPA;S:" + apName + ";P:12345678;;";
  }
  ui_qrcodedata = qrcodeurl.c_str();
  lv_qrcode_update(ui_qrcode_obj, ui_qrcodedata, strlen(ui_qrcodedata));
  lv_obj_center(ui_qrcode_obj);
  
  // Initialize time and date from compiler
  time_init();
  
  // Create Sensor Task
  xTaskCreatePinnedToCore(sensorData, "sensorData", 10000, NULL, 2, &myTaskHandle, 1);
  
  // Add the new task to the watchdog
  esp_task_wdt_add(myTaskHandle);
}

void loop() {  
  wm.process();  // Update Wifi Manager
  lv_handler();  // Update UI
  update_time(); // Update time and date on UI
  // Reset the watchdog timer
  esp_task_wdt_reset();
}

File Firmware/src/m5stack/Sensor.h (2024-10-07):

// pm1.h
#pragma once

#include <SensirionI2CSen5x.h>
#include <Wire.h>
#include "ui/ui.h"
#include <WiFi.h>
#include <PubSubClient.h>

#define MAXBUF_REQUIREMENT 48
#define CHART_DATA_LENGTH 15
#define DATA_FREQ 150

#if (defined(I2C_BUFFER_LENGTH) &&                 \
     (I2C_BUFFER_LENGTH >= MAXBUF_REQUIREMENT)) || \
    (defined(BUFFER_LENGTH) && BUFFER_LENGTH >= MAXBUF_REQUIREMENT)
#endif

typedef struct{
    float pm1 = 0;
    float pm25 = 0;
    float pm10 = 0;
    float pm4 = 0;
    float tvoc = 0;
    int pm1_max = 0;
    int pm25_max = 0;
    int pm10_max = 0;
    int pm4_max = 0;
    int tvoc_max = 0;
    int count = 0;
} Sensor_t;

typedef struct {
  float Cp_Lo; // Low concentration breakpoint
  float Cp_Hi; // High concentration breakpoint
  int Ip_Lo;   // Low index breakpoint
  int Ip_Hi;   // High index breakpoint
} AQIBreakpoint;

// Function to calculate sub-index
int calculateSubIndex(float Cp, AQIBreakpoint bp) {
  float Ip = ((bp.Ip_Hi - bp.Ip_Lo) / (bp.Cp_Hi - bp.Cp_Lo)) * (Cp - bp.Cp_Lo) + bp.Ip_Lo;
  return (int)round(Ip);
}

// Function to get breakpoint for a given concentration
AQIBreakpoint getBreakpoint(float Cp, AQIBreakpoint bps[], int numBps) {
  for (int i = 0; i < numBps; i++) {
    if (Cp >= bps[i].Cp_Lo && Cp <= bps[i].Cp_Hi) {
      return bps[i];
    }
  }
  // Return the highest breakpoint if Cp exceeds the range
  return bps[numBps - 1];
}

// Function to get AQI category
String getAQICategory(int aqi) {
  if (aqi >= 0 && aqi <= 50) return "Good";
  else if (aqi <= 100) return "Satisfactory";
  else if (aqi <= 150) return "Moderate";
  else if (aqi <= 200) return "Unhealthy";
  else if (aqi <= 300) return "Very Unhealthy";
  else return "Hazardous";
}

uint32_t getAQIColor(int aqi) {
  if (aqi >= 0 && aqi <= 50) return 0x00E400; // Good
  else if (aqi <= 100) return 0x9CFF9C; // Satisfactory
  else if (aqi <= 150) return 0xFFFF00; // Moderate
  else if (aqi <= 200) return 0xFF7E00; // Unhealthy
  else if (aqi <= 300) return 0xFF0000; // Very Unhealthy
  else return 0x8F3F97; // Hazardous
}

// PM2.5 Breakpoints
AQIBreakpoint pm1Bps[] = {
  {0.0, 8.0, 0, 50},
  {8.1, 25.4, 51, 100},
  {25.5, 35.4, 101, 150},
  {35.5, 50.4, 151, 200},
  {50.5, 75.4, 201, 300},
  {75.5, 500.4, 301, 500}
};

// PM2.5 Breakpoints
AQIBreakpoint pm4Bps[] = {
  {0.0, 35.0, 0, 50},
  {35.1, 75.4, 51, 100},
  {75.5, 125.4, 101, 150},
  {125.5, 175.4, 151, 200},
  {175.5, 250.4, 201, 300},
  {250.5, 500.4, 301, 500}
};

// PM2.5 Breakpoints
AQIBreakpoint pm25Bps[] = {
  {0.0, 12.0, 0, 50},
  {12.1, 35.4, 51, 100},
  {35.5, 55.4, 101, 150},
  {55.5, 150.4, 151, 200},
  {150.5, 250.4, 201, 300},
  {250.5, 500.4, 301, 500}
};

// PM10 Breakpoints
AQIBreakpoint pm10Bps[] = {
  {0, 54, 0, 50},
  {55, 154, 51, 100},
  {155, 254, 101, 150},
  {255, 354, 151, 200},
  {355, 424, 201, 300},
  {425, 604, 301, 500}
};

// TVOC Breakpoints (example values)
AQIBreakpoint tvocBps[] = {
  {0.0, 300, 0, 50},
  {300, 500, 51, 100},
  {500, 1000, 101, 150},
  {1000, 3000, 151, 200},
  {4000, 5000, 201, 300},
  {5000, 10000, 301, 500}
};

SensirionI2CSen5x sen5x;
Sensor_t sensor_data;

WiFiClient espClient;
PubSubClient client(espClient);

String deviceName = "";

// MQTT Server Details
const char* mqtt_server = "mqtt.oizom.com";
const char* username = "xxxx";
const char* password = "xxxx";

lv_chart_series_t * ui_PM1chart_series_1 = { 0 };
static lv_coord_t ui_PM1chart_series_1_array[CHART_DATA_LENGTH] = { 0 };
        
lv_chart_series_t * ui_PM25chart_series_1 = { 0 };
static lv_coord_t ui_PM25chart_series_1_array[CHART_DATA_LENGTH] = { 0 };

lv_chart_series_t * ui_PM4chart_series_1 = { 0 };
static lv_coord_t ui_PM4chart_series_1_array[CHART_DATA_LENGTH] = { 0 };

lv_chart_series_t * ui_PM10chart_series_1 = { 0 };
static lv_coord_t ui_PM10chart_series_1_array[CHART_DATA_LENGTH] = { 0 };

lv_chart_series_t * ui_TVOCchart_series_1 = { 0 };
static lv_coord_t ui_TVOCchart_series_1_array[CHART_DATA_LENGTH] = { 0 };

void callback(char* topic, byte* payload, unsigned int length) {
  // handle message arrived
}

boolean reconnect() {
  if(!client.connected())
  {
    String clientId = "AIROWL";
    clientId += String(random(0xffffff), HEX);
    if (client.connect(clientId.c_str(), username, password)) {
        M5.Log.println("MQTT Connected");
    }
  }
  return client.connected();
}

void setupMQTT()
{
    client.setServer(mqtt_server, 1883);
    client.setCallback(callback);
}

void setupCharts()
{
    ui_PM1chart_series_1 = lv_chart_add_series(ui_PM1chart, lv_color_hex(0x41b4d1), LV_CHART_AXIS_PRIMARY_Y);
    lv_chart_set_ext_y_array(ui_PM1chart, ui_PM1chart_series_1, ui_PM1chart_series_1_array);
    lv_chart_set_range( ui_PM1chart, LV_CHART_AXIS_PRIMARY_Y, 0, 50);

    ui_PM25chart_series_1 = lv_chart_add_series(ui_PM25chart, lv_color_hex(0x41b4d1), LV_CHART_AXIS_PRIMARY_Y);
    lv_chart_set_ext_y_array(ui_PM25chart, ui_PM25chart_series_1, ui_PM25chart_series_1_array);
    lv_chart_set_range( ui_PM25chart, LV_CHART_AXIS_PRIMARY_Y, 0, 50);

    ui_PM10chart_series_1 = lv_chart_add_series(ui_PM10chart, lv_color_hex(0x41b4d1), LV_CHART_AXIS_PRIMARY_Y);
    lv_chart_set_ext_y_array(ui_PM10chart, ui_PM10chart_series_1, ui_PM10chart_series_1_array);
    lv_chart_set_range( ui_PM10chart, LV_CHART_AXIS_PRIMARY_Y, 0, 50);

    ui_PM4chart_series_1 = lv_chart_add_series(ui_PM4chart, lv_color_hex(0x41b4d1), LV_CHART_AXIS_PRIMARY_Y);
    lv_chart_set_ext_y_array(ui_PM4chart, ui_PM4chart_series_1, ui_PM4chart_series_1_array);
    lv_chart_set_range( ui_PM4chart, LV_CHART_AXIS_PRIMARY_Y, 0, 50);

    ui_TVOCchart_series_1 = lv_chart_add_series(ui_TVOCchart, lv_color_hex(0x41b4d1), LV_CHART_AXIS_PRIMARY_Y);
    lv_chart_set_ext_y_array(ui_TVOCchart, ui_TVOCchart_series_1, ui_TVOCchart_series_1_array);
    lv_chart_set_range( ui_TVOCchart, LV_CHART_AXIS_PRIMARY_Y, 0, 100);
}
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

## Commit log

2024-09-20 UI updated and labels, chart values are modified.
    UI updated,
    Pm1.h file created, to drive values of parameters into labels on the screen.
    Sensor data to be fed into this file.
    uiscreen files can be used to overwrite the static values of the graph defined in squareline studio.
2024-10-02 KiCAD Project File
    [AirOwl_v1-CuBottom.gbr, AirOwl_v1-CuTop.gbr, AirOwl_v1-EdgeCuts.gbr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]
2024-10-04 Air owl 3D files
    [Facia back plate 5mm (Black).dxf, Front facia 1mm.dxf, Owl_2.0_component_case_V2.4.4.3MF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]
2024-10-07 BOM Added
2024-10-07 design files updated
    [Facia back plate 5mm (Black).dxf, Front facia 1mm.dxf, Owl_2.0_component_case_V2.4.4.3MF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]
2024-10-07 2design folders created
    [Facia back plate 5mm (Black).dxf, Front facia 1mm.dxf, Owl_2.0_component_case_V2.4.4.3MF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]
2024-10-11 PCB renders
    [AirOwl_v1.kicad_pcb, AirOwl_v1.kicad_sch, AirOwl_v1.step]
2024-10-11 Update README.md | Mounting Board

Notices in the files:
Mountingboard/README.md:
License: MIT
